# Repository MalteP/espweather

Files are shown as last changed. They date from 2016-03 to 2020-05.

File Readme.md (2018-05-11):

# ESP8266 WiFi Weather Sensor

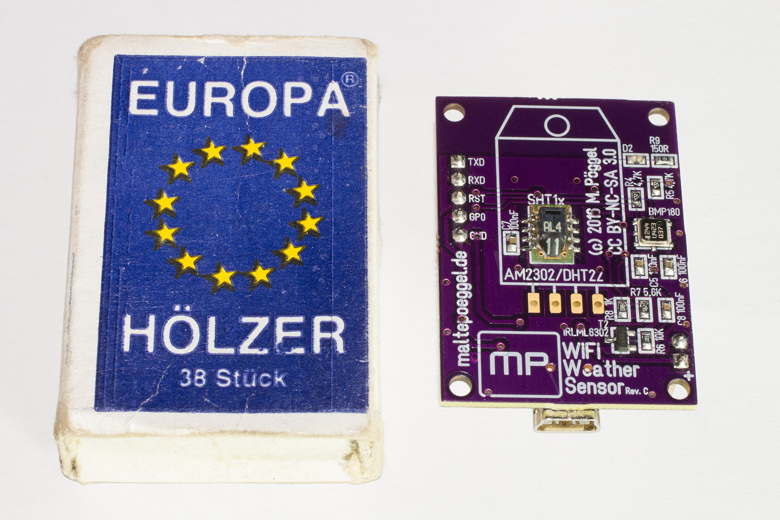
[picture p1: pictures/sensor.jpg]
Picture: ESP8266 WiFi Weather Sensor


## Project overview

The WiFi Weather Sensor is a tiny weather station based on the ESP8266 SOC. It will push the measured temperature, humidity, pressure and battery voltage to the cloud or local servers in defined intervals. Configuration is done by using a simple web browser.

The sensor can be powered using a standard USB power supply or any batteries with a voltage of 3.5 to 6.5V. If inactive, the sensor will enter low power standby. A set of four AA batteries e.g. will last for about one month. The system will also switch off if the voltage drops below 3.0V to safe LiPo batteries. For recharging you might combine it with a solar charger.

## Building the hardware

#### Ordering the parts

Most of the components are available from [Reichelt Elektronik](http://www.reichelt.de/), some more specific parts at [Farnell](http://www.farnell.com/), [Mouser](http://www.mouser.com/) or [Digikey](http://www.digikey.com/). For the ESP-12 (PCB antenna only) or ESP-07 module (PCB antenna + U.FL connector) have a look at [eBay](http://www.ebay.com/) or [Aliexpress](http://www.aliexpress.com/).

As temperature / humidity sensor either SHT11/SHT15 (more accurate) or AM2302/DHT22 (lower price) are possible. The connected sensor is detected automatically. Barometric pressure is measured by using the MS5637 sensor. (Or BMP180 on v1 circuit board)

Here's a list of all components: [Bill of materials (PDF)](documents/parts_v2.pdf)

#### Circuit board

The circuit board is double-sided and plated-through. Because of that i'll recommend ordering it from a PCB manufacturer. Gerber files are included in the GIT repository. Possible good value PCB fabs are [OSH-Park (USA)](http://www.oshpark.com/), [Itead-Studio (China)](http://www.itead.cc/open-pcb.html) or [Dirty Cheap Circuit Boards (China)](http://www.dirtypcbs.com/).

The design is already uploaded to OSH Park, just order it here:

[WiFi Weather Sensor (Version 2) Circuit Board](http://www.oshpark.com/shared_projects/pmVMF4gY)

[WiFi Weather Sensor (Version 1 rev. D) Circuit Board](http://www.oshpark.com/shared_projects/jZi4VgjG)

#### Schematic

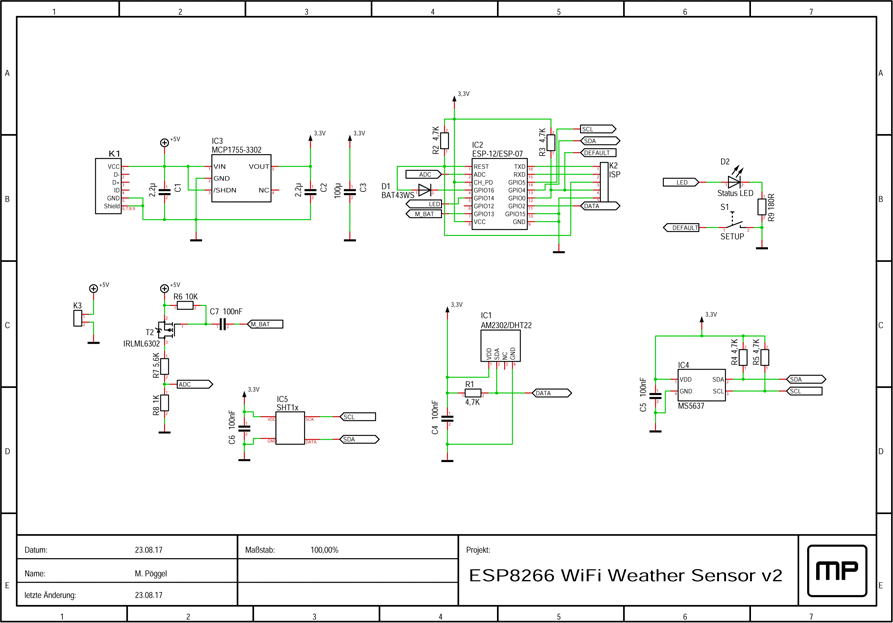
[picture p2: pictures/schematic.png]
Schematic


The LDO IC3 regulates the battery voltage down to 3.3V for power supply of the whole system. Battery voltage is monitored through the voltage divider R7 / R8 which is switched on by FET T2 only during measurement [to reduce power consumption](http://www.jeelabs.org/2013/05/18/zero-power-measurement-part-2/). The barometric pressure sensor MS5637 (IC4) and temperature / humidity sensor SHT11 (IC5) are connected to the ESP8266 module IC2 via I²C bus. Alternatively the temperature / humidity sensor AM2302/DHT22 (IC1) can be used. It is connected using a single wire bus. Status LED (D2) and a setup button (S1) are connected directly to the WiFi module. R3 is used as pull-up resistor for the button, R2 for the reset pin. In low power standby mode XPD_DCDC (GPIO16) is pulled low on wakeup timer event. I've connected it to the reset pin through a shottky diode (D1), because otherwise GPIO16 seemed to be at high level and there was a few ten milliamps of current flowing during reset if flashed via serial connection.

#### Assembling the board

The top side (except for the SHT11 sensor) is soldered in a reflow oven. Just apply solder paste through a CNC cut stencil and bake the board with the appropriate temperature profile. If you don't own a reflow oven, a hot air soldering station might work, too.

The bottom side is assembled using a conventional soldering iron. It's the best practice to start with the smallest components first. If the sensor should run on batteries, don't forget to remove the red LED from the ESP8266 module.

## Preparing the hardware to flash

All ESP8266 modules have a pre-installed bootloader which allows simple firmware flashing via serial connection. A 3.3V TTL USB serial adapter is needed. I recommend those with FT232 chipset.

Connect the pin header of the board to the serial adapter as follows:

| Weather sensor | Serial adapter |
| --- | --- |
| TXD | TXD |
| RXD | RXD |
| RST | RTS |
| GP0 | DTR |
| GND | GND |

## Building the firmware

If you don't want to modify the firmware, you might skip the next steps and [flash the precompiled firmware](#flashing-the-precompiled-firmware).

#### Installing the toolchain

First we will install all necessary packages to compile the toolchain. On a minimal Fedora 26 Linux use the following commands:

```
sudo dnf install make autoconf automake libtool gcc gcc-c++ gperf flex bison texinfo gawk ncurses-devel expat-devel python pyserial python-devel sed git unzip wget bzip2 patch help2man

sudo dnf install http://download1.rpmfusion.org/free/fedora/rpmfusion-free-release-$(rpm -E %fedora).noarch.rpm 
sudo dnf install http://download1.rpmfusion.org/nonfree/fedora/rpmfusion-nonfree-release-$(rpm -E %fedora).noarch.rpm
sudo dnf install unrar
```

If you are using Debian or Ubuntu Linux, [just have a look at the toolchain documentation for installing the needed packages](https://github.com/pfalcon/esp-open-sdk#requirements-and-dependencies). After that you may continue as described below.

Now we're ready to download and compile the ESP8266 toolchain. This process may take a few minutes, depending on your Internet connection and CPU speed, so you better get yourself a cup of tea (or coffee).

```
git clone --recursive https://github.com/pfalcon/esp-open-sdk.git

cd esp-open-sdk
make

cd ..
```

If no errors have occurred, we are ready to finish the installation. I prefer moving the toolchain out of my home directory to /opt, but you may also leave it there and change the paths in the environment variables.

```
sudo mv esp-open-sdk /opt/esp-open-sdk
```

Open your `.bashrc` file with your favorite editor and add the following lines at the end of the file:

```
export PATH=/opt/esp-open-sdk/xtensa-lx106-elf/bin:$PATH
export XTENSA_TOOLS_ROOT=/opt/esp-open-sdk/xtensa-lx106-elf/bin/
export SDK_BASE=/opt/esp-open-sdk/sdk
export ESPTOOL=/opt/esp-open-sdk/esptool/esptool.py
export ESPPORT=/dev/ttyUSB0
```

The changes take effect after a new shell is opened, so log out or open a new terminal window.

#### Installing yui-compressor

yui-compressor is written in Java, so we'll need to install the Java package:

```
sudo dnf install java
```

If you are using Debian or Ubuntu Linux instead of Fedora, [install the OpenJDK JRE.](https://wiki.ubuntuusers.de/Java/Installation/OpenJDK/)

Now download the precompiled .jar file to a folder and also copy it to /opt:

```
mkdir yuicompressor
wget https://github.com/yui/yuicompressor/releases/download/v2.4.8/yuicompressor-2.4.8.jar
mv yuicompressor-2.4.8.jar yuicompressor/yuicompressor.jar
sudo mv yuicompressor /opt/yuicompressor
```

A small wrapper script is needed to execute `yui-compressor` from the `makefile`. Open it with your favorite editor by typing:

```
sudo vi /usr/bin/yui-compressor
```

And add the following lines:

```
#!/bin/sh
java -jar /opt/yuicompressor/yuicompressor.jar $*
```

Now make the script executable:

```
sudo chmod +x /usr/bin/yui-compressor
```

#### Compiling the firmware

Just clone this repository and change into its directory:

```
git clone https://github.com/MalteP/espweather.git
cd espweather
cd firmware
```

Compile the firmware by typing `make`.

```
make
```

Flash firmware and filesystem partition by typing:

```
make flash
make htmlflash
```

If the serial port is not /dev/ttyUSB0, you may add (for example) `ESPPORT=/dev/ttyUSB1` to both `make` commands or change your environment variables.

If the firmware is running, the orange LED on the board should start flashing.

#### Troubleshooting

If the blue LED is constantly flickering, there might be a problem with the calibration data which is stored in flash memory. The position depends on the size of flash determined from the firmware header. Just flash the default calibration data again:

```
make defaultflash
```

After cycling power of the board, the firmware should run fine. The precompiled binary includes calibration data at the correct position.

## Flashing the precompiled firmware

If you don't want to compile the firmware yourself, just skip all "[Building the firmware](#building-the-firmware)" steps above.

You might use [NodeMCU Flasher](https://github.com/nodemcu/nodemcu-flasher) on Windows to flash the precompiled binaries. Open it, change to the "Config" tab and choose the firmware binary by clicking the gear-wheel button. Click the drop-down list on the right side to select the flash section 0x00000. Change back to the "Operation" tab, select the COM port your serial adapter is connected to, and click the "Flash" button.

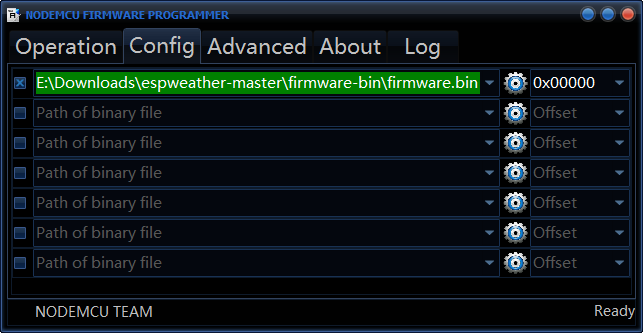
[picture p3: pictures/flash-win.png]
Screenshot: NodeMCU Flasher - Config tab


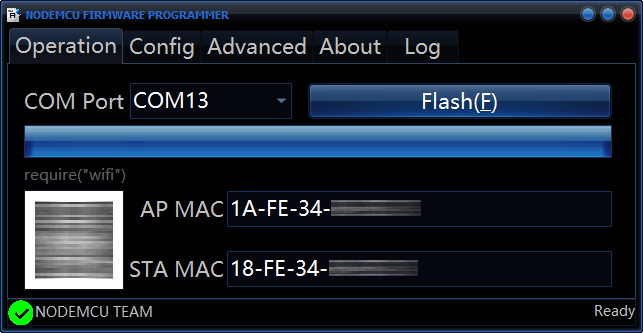
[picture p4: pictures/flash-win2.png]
Screenshot: NodeMCU Flasher - Operation tab


## Hardware setup

There are two modes inside the firmware, normal mode and configuration mode. In normal mode the sensor will measure and push data to the cloud. In configuration mode the sensor acts as wireless access point and is configured via a standard web browser.

#### Normal mode

The sensor will measure temperature, humidity, barometric pressure and battery voltage and push these values to the configured server. After that it will enter deep sleep standby.
At the first start after the battery has been connected, the sensor will stay active for one minute. You may press the button for 3-4sec to switch to configuration mode.

The status is shown by the orange LED, flashing in 1s intervals

| no. of flashes | Status |
| --- | --- |
| 1x | Waiting for WiFi / DHCP |
| 2x | Push data |
| 3x | Server error |
| 4x | First start, waiting |

#### Configuration mode

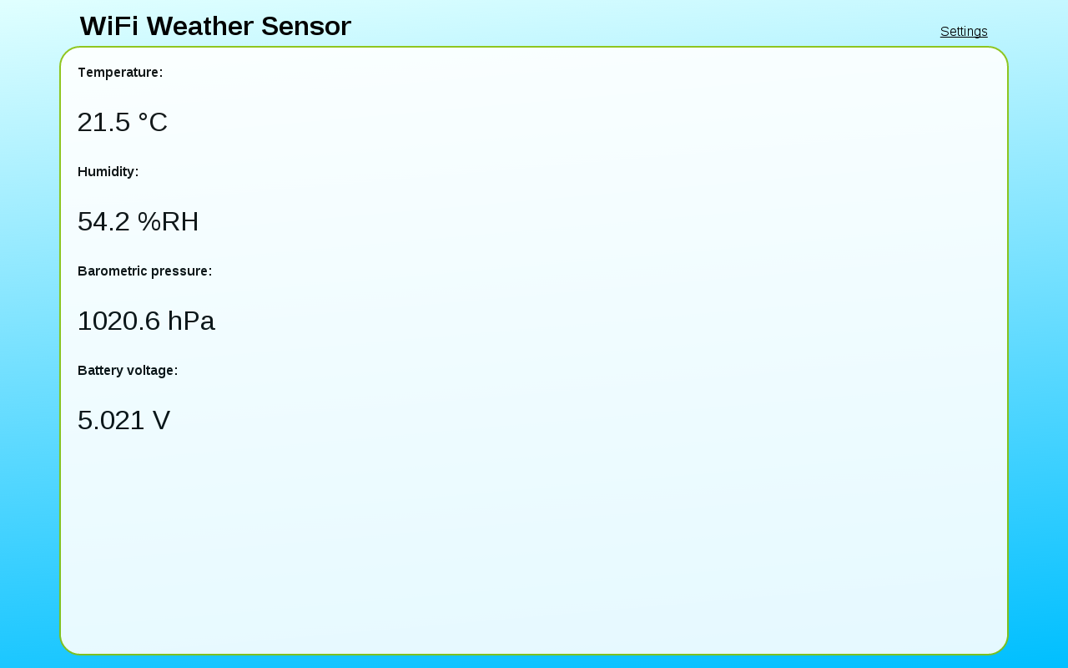
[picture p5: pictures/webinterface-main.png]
Screenshot: Webinterface - Main page


In configuration mode the orange LED will blink at 1Hz clock. Use your computer to connect to the WiFi ESP_xxxx (no encryption) and open http://192.168.4.1/ in your browser.
It will show measured values on the main page, but they may not be very accurate because the WiFi module will heat up the sensors. (This won't affect normal mode because the sensor is only active for ~20sec and will "cool down" during standby periods!)
To leave configuration mode, hold the button for 3-4sec. To erase all configuration data, hold the button for about 10sec.

Click on the button "Settings" at the top right side. The default username is "admin" with password "insecure".

Hint: If you'd like to use an encrypted configuration WiFi, just uncomment the WIFI_PASS definition in user/config.h before compiling.

##### Network settings

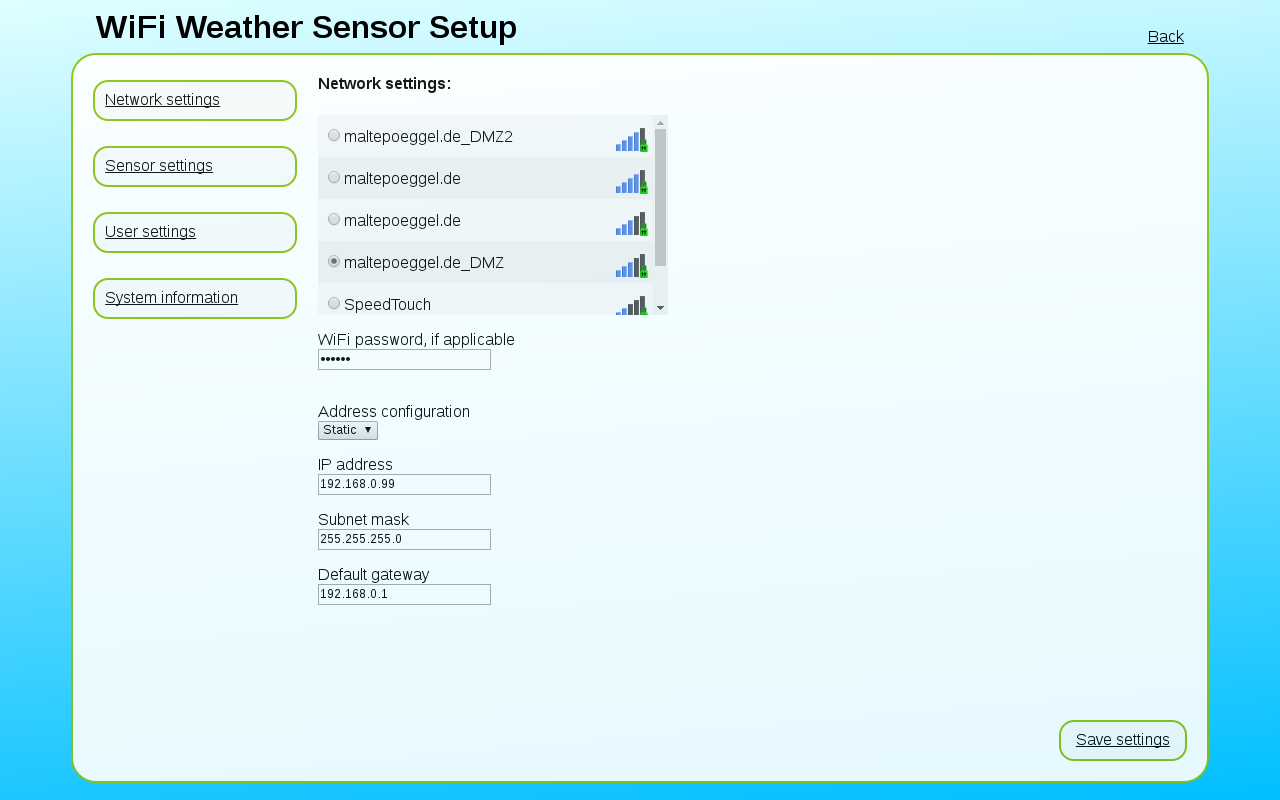
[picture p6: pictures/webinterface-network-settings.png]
Screenshot: Webinterface - Network settings


Just choose the WiFi you want to connect to and enter the password if it is encrypted. 
It might be useful to set up a guest network in your router for security reasons.

##### Sensor settings

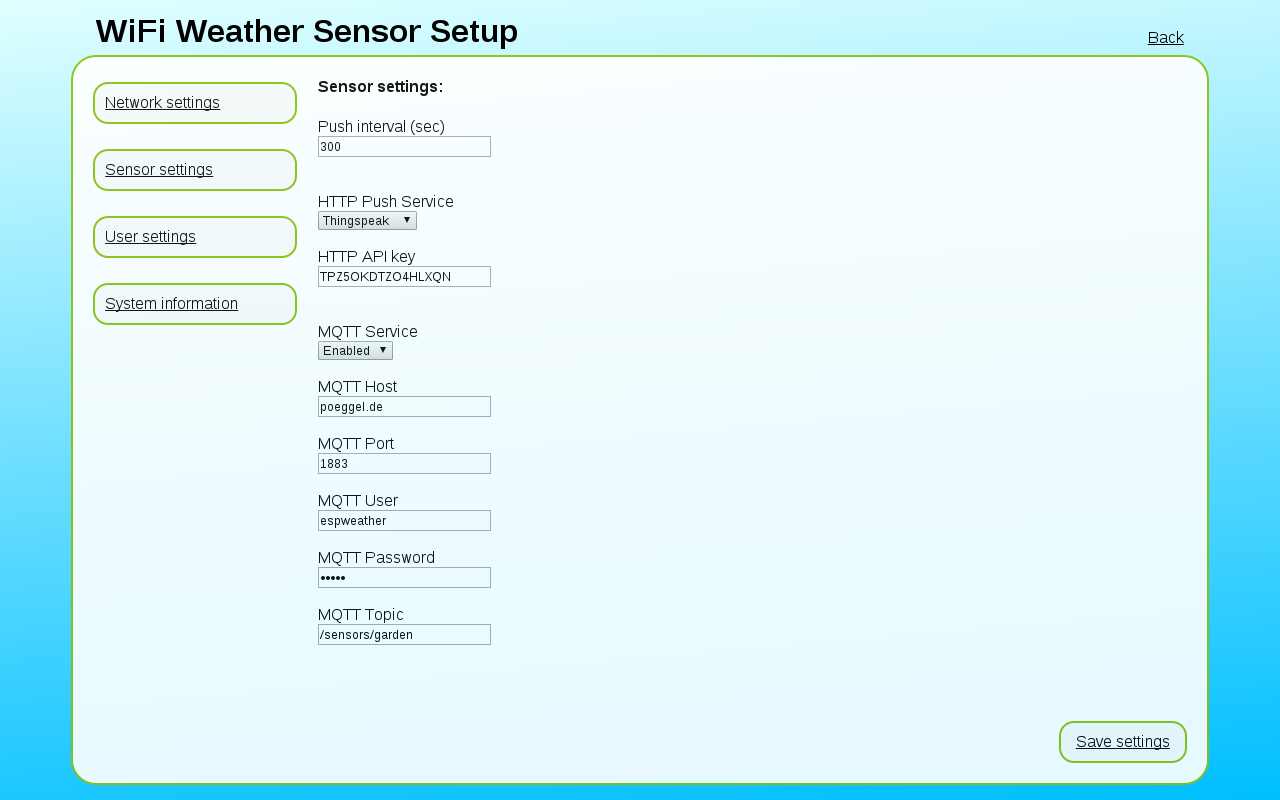
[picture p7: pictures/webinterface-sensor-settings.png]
Screenshot: Webinterface - Sensor settings


On the sensor settings tab, you may change the interval the sensor data is pushed to HTTP and / or MQTT servers. Per default this is set to 300sec (5min).

As cloud services [Thinkspeak](http://www.thingspeak.com/) and [adafruit.io](http://io.adafruit.com/) are available. It is also possible to use a custom URL with placeholders which are replaced by measured values.

| Placeholder | Value |
| --- | --- |
| %t | Temperature |
| %h | rel. Humidity |
| %p | Barometic pressure |
| %v | Battery voltage |
| %r | WiFi signal strength |

If you like to use MQTT, just setup a server software like [mosquitto](http://www.mosquitto.org/) and configure host, port, user and password. The sensor will publish data on [topic]/temperature, /humidity, /pressure, /voltage and /rssi. Different clients may subscribe and receive data immediately after it is published.

##### User settings

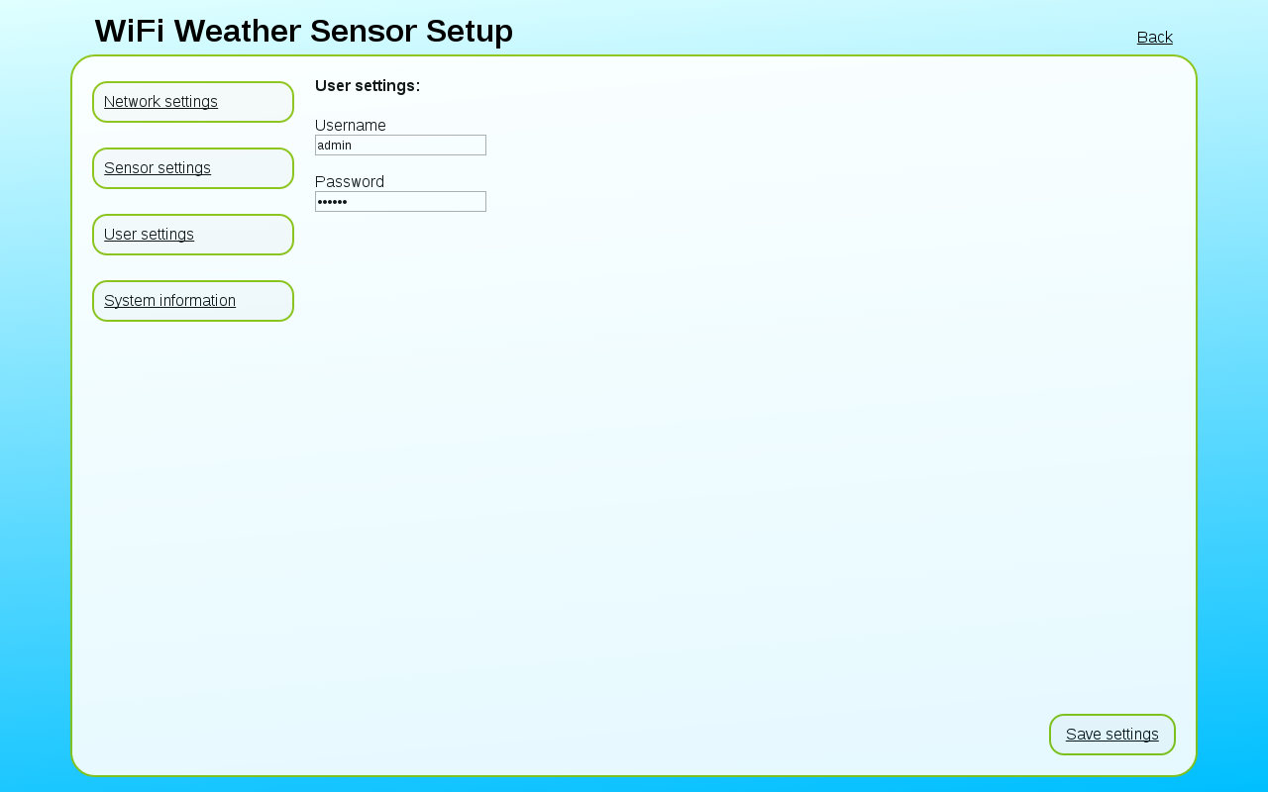
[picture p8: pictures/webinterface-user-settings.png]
Screenshot: Webinterface - User settings


You may change the default username and password for configuration login here.

##### System information

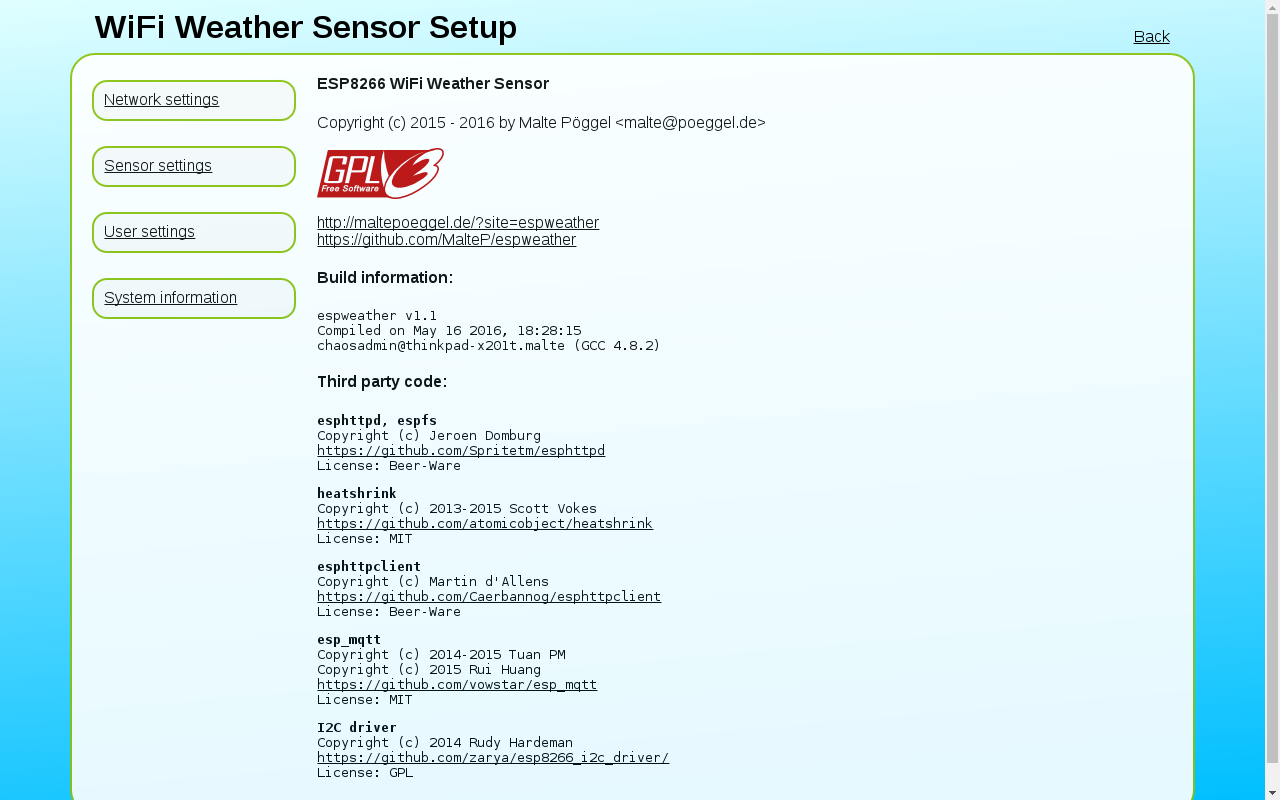
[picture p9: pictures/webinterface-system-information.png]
Screenshot: Webinterface - System information


This shows some nice information about the sensor and code used.

## License

The firmware is released under the terms of [GNU GPL v3](http://www.gnu.org/licenses/gpl-3.0.en.html), circuit board is licensed [CC BY-NC-SA](https://www.creativecommons.org/licenses/by-nc-sa/3.0/).

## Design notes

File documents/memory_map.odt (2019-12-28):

## 4 Mbit (512 KByte)

| Start | End | Size | Description
User | 0x00000 | 0x1FFFF | 131072 bytes | Main application
| | | | firmware/0x00000.bin
| 0x20000 | 0x36FFF | 94208 bytes | ESP filesystem (Web UI)
| | | | Included in main application binary.
SDK | 0x36000 | 0x79FFF | 278528 bytes | SDK libraries
| | | | firmware/0x36000.bin
Config | 0x7A000 | 0x7AFFF | 4096 bytes | Application configuration
| | | | Written by application binary.
| 0x7B000 | 0x7BFFF | 4096 bytes | Calibration data
| | | | blank.bin
| 0x7C000 | 0x7DFFF | 8192 bytes | Default configuration
| | | | esp_init_data_default.bin
| 0x7E000 | 0x7FFFF | 8192 bytes | WiFi configuration
| | | | blank.bin

## 8 Mbit (1024 KByte)

| Start | End | Size | Description
User | 0x00000 | 0x1FFFF | 131072 bytes | Main application
| | | | firmware/0x00000.bin
| 0x20000 | 0x36FFF | 94208 bytes | ESP filesystem (Web UI)
| | | | Included in main application binary.
SDK | 0x36000 | 0xF9FFF | 802816 bytes | SDK libraries
| | | | firmware/0x36000.bin
Config | 0xFA000 | 0xFAFFF | 4096 bytes | Application configuration
| | | | Written by application binary.
| 0xFB000 | 0xFBFFF | 4096 bytes | Calibration data
| | | | blank.bin
| 0xFC000 | 0xFDFFF | 8192 bytes | Default configuration
| | | | esp_init_data_default.bin
| 0xFE000 | 0xFFFFF | 8192 bytes | WiFi configuration
| | | | blank.bin

WiFi Weather Sensor - Flash Memory Map

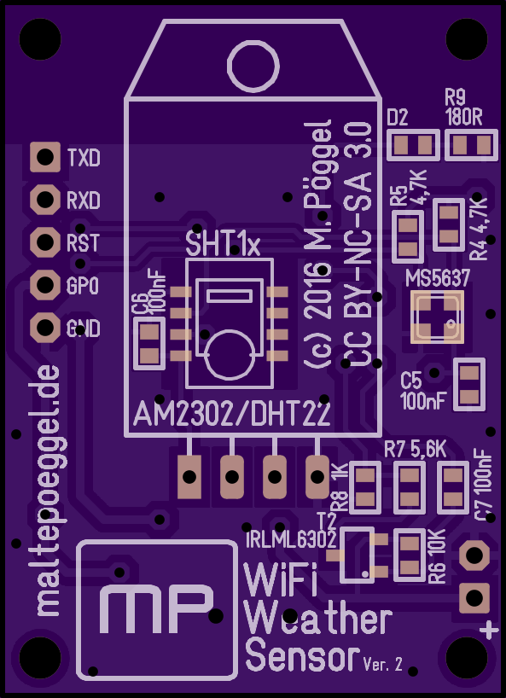
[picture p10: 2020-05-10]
pictures/v2_top.png

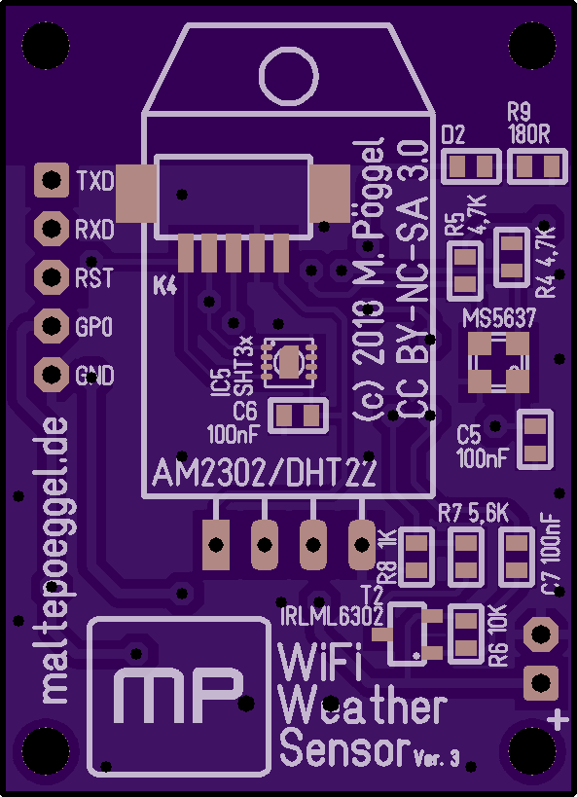
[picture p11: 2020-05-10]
pictures/v3_top.png

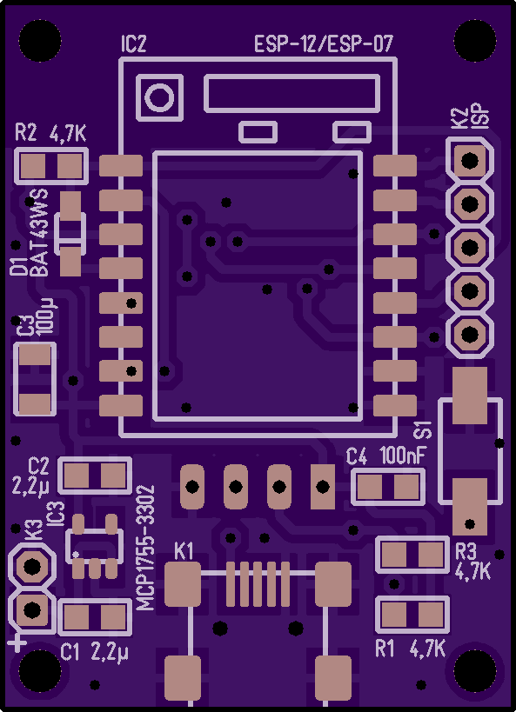
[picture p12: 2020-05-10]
pictures/v3_btm.png

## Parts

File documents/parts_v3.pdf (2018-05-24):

Name | Value | Gehäuse | Bestellnummer | Distributor | Price | Notes
C1 | 2,2µ | 0805 | X7R-G0805 2,2/25 | Reichelt | 0,08 €
C2 | 2,2µ | 0805 | X7R-G0805 2,2/25 | Reichelt | 0,08 €
C3 | 100µ | 1206 | X5R-G1206 100/6 | Reichelt | 0,45 €
C4 | 100nF | 0805 | X7R-G0805 100N | Reichelt | 0,02 €
C5 | 100nF | 0603 | X7R-G0603 100N | Reichelt | 0,02 €
C6 | 100nF | 0603 | X7R-G0603 100N | Reichelt | 0,02 €
C7 | 100nF | 0603 | X7R-G0603 100N | Reichelt | 0,02 €
D1 | BAT43WS | SOD323 | BAT 43WS | Reichelt | 0,05 €
D2 | SMD LED orange | 0603 | LA L296 | Reichelt | 0,15 €
IC1 | AM2302/DHT22 | - | - | eBay | 0,00 € Cheaper sensor. Use either IC1 or IC5
IC2 | ESP-12/ESP-07 | - | - | eBay | 5,00 € ESP07: U.FL jack for external antenna
IC3 | MCP1755-3302 | SOT23/5 | 2361992 | Farnell | 0,62 €
IC4 | MS5637 | | 893-7168 | RS-Components | 4,30 €
IC5 | SHT3x | - | 2474218 | Farnell | 5,75 € More precise measurements than IC1
K1 | Mini USB Type B | - | USB BWM SMD | Reichelt | 0,28 €
K2 | Pin header 1x05 | - | MPE 087-1-005 | Reichelt | 0,12 €
K3 | Pin header 1x02 | - | MPE 087-1-002 | Reichelt | 0,05 €
K4 | 53261-0571 | - | MOLEX 532610571 | Reichelt | 0,28 €
R1 | 4,7K | 0805 | SMD-0805 4,70K | Reichelt | 0,03 €
R2 | 4,7K | 0805 | SMD-0805 4,70K | Reichelt | 0,03 €
R3 | 4,7K | 0805 | SMD-0805 4,70K | Reichelt | 0,03 €
R4 | 4,7K | 0603 | SMD-0603 4,7K | Reichelt | 0,03 €
R5 | 4,7K | 0603 | SMD-0603 4,7K | Reichelt | 0,03 €
R6 | 10K | 0603 | SMD-0603 10K | Reichelt | 0,03 €
R7 | 5,6K | 0603 | SPR-0603 5,60K | Reichelt | 0,25 €
R8 | 1K | 0603 | SPR-0603 1,00K | Reichelt | 0,25 €
R9 | 180R | 0603 | SMD-0603 180 | Reichelt | 0,03 €
S1 | KSR221G SMT Switch | - | 1201421 | Farnell | 0,54 €
T2 | IRLML6302 | SOT23/3 | IRLML 6302 | Reichelt | 0,19 €
PCB | Circuit board | - | - | OSH Park | 3,00 €
21,73 €

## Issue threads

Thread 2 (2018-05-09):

Thingspeak Field 1 & 2 not updating

nabontra, 2018-05-09:
Thank you for sharing your project! I assembled your OSHpark board and uploaded the precompiled firmware. I am getting successful data readouts from all sensors when in configuration mode through the ESP Access Point. When using the Thingspeak API, only fields 3 and 4 seem to be making it through. I am assuming the protocols have changed on Thingspeak in the past two years since they have been purchased by MathWorks, but it looks like the only API change are to an HTTPS domain. Have you experienced this recently?
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

MalteP, 2018-05-09:
Hi Nick,
which type of temperature / humidity sensor are you using?

MalteP, 2018-05-09:
I've fixed some timing issues in #b80f9c2 which might cause the first read of DHT22 sensors to fail. You'll better use the development branch firmware, but there currently are no precompiled binaries. I'll check my ESP toolchain and send you an email, just give me a few minutes ;-)

MalteP, 2018-05-16:
Did the development firmware solve your issue?

Closed 2019-01-22.

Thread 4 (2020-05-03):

Humidity data in Thingspeak occasionally missing

DK3LJ, 2020-05-03:
Hardware is espweather v3 with current firmware 221-8m.bin, sensor is AM2302.

ESPweather is set up to feed data into Thingspeak with 5 fields: (temperature, humidity, pressure, voltage, RSSI) in 5 minute intervals. Power supply is via USB cable from a USB charger.

In most cases, humidity data is missing from the data in Thingspeak. However, after a reboot (with or without going into config mode to check the data), the next few tramsissions are fine, then drop off again.

Feeds CSV export is attached. Any ideas?

[feeds.txt](https://github.com/MalteP/espweather/files/4570643/feeds.txt)

MalteP, 2020-05-03:
As the AM2302 is of very poor quality, resolution and there is no long time stability data available from the manufacturer, i would suggest to use **any** other sensor if possible.

Prices for the BME280 dropped, so this would be my choice for low budget sensors. I can provide crimped cables with Molex / Jumper connectors if you are interested. (Hint: Select address 0x77 by soldering the solder bridge on the "GYBMEP" board to +3V) Btw: My favourite sensor combination is MS5637 / SHT35.

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

SDK 2.2.1 is supported since the last commit. Might be timing issues; might be long cables. Are there any other sensors on your circuit board (e.g. barometric pressure)?

The sensor selection code will default to the sensor with the highest resolution available, so if the AM2302 is not detected properly, you might get the temperature readings from your MS5637.

Please test if the values are also missing in the SDK 2.1.0 version i sent you. If so, we'll need to analyze the protocol with a storage oscilloscope and fine-tune timing parameters in dht22.h. And maybe build a version with some debug printf()'s. But i don't have much time because i'm working on other projects right now...

MalteP, 2020-05-05:
I did some testing and found out that i can reproduce your issue. When the board is booted up, my logic analyzer doesn't show me any response from the sensor when opening /sensors.cgi (which fetches the sensor data in config mode) directly in my browser. After some minutes the sensor is suddenly responding. But if the board is then rebooted, the communication breaks again.

After that i played around with the start pulse length, added 100nF or 10µF capacitors to the sensor, changed the pull up resistor value; no success...

Then i found a board with an old sensor (maybe bought it years ago when i started developing this project) and desoldered it. I changed the sensor in my test setup to the old one. It is always read out. After every reset, there are no problems at all!

Maybe the new sensor is fake, maybe they changed the firmware, but i guess we can not fix this hardware issue in the DHT22 driver...

Btw there are similar reports for the Tasmota project:
https://github.com/arendst/Tasmota/issues/3187

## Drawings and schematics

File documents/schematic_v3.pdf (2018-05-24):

D+ | 3 D- | 2 VCC | 1 K1

A

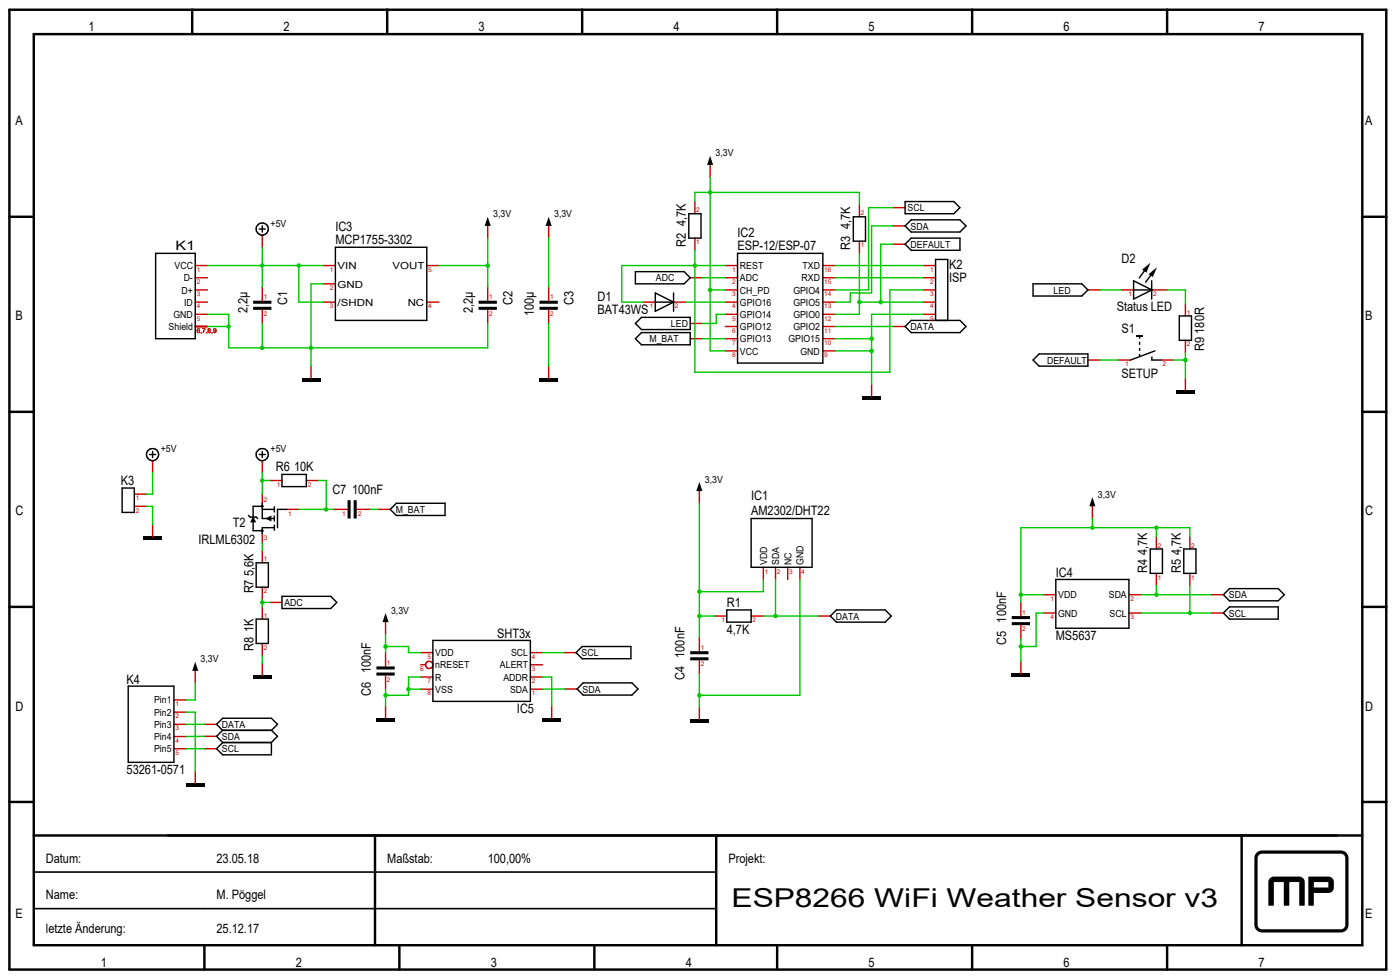
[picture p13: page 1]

Datum: 23.05.18 | Maßstab: 100,00% | Projekt:

Name:

letzte Änderung: 25.12.17

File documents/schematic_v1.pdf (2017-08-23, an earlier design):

K1

A

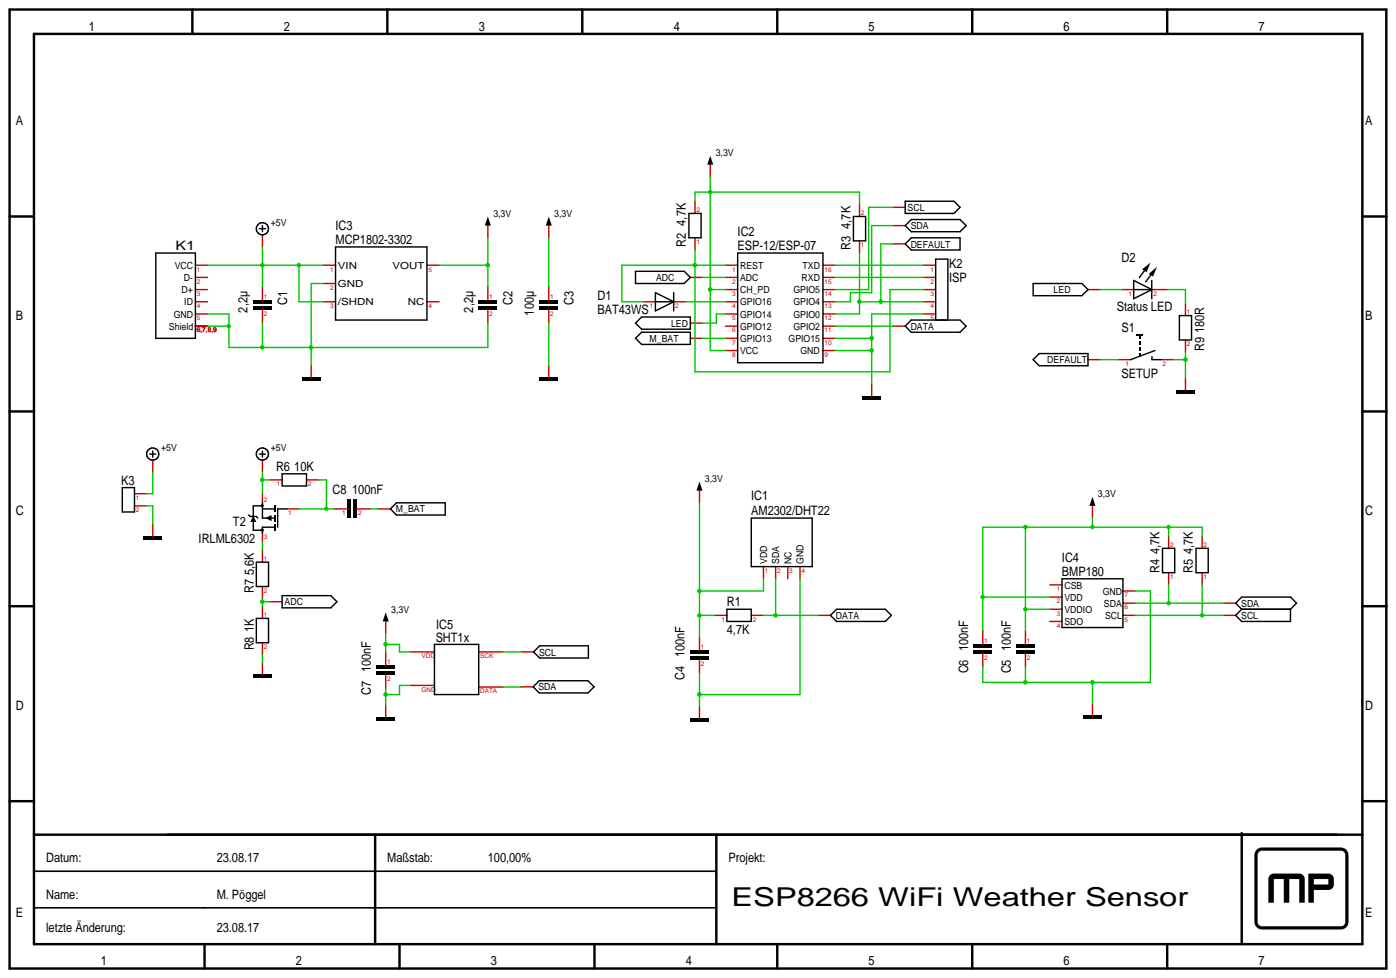
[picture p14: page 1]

Datum: 23.08.17 | Maßstab: 100,00% | Projekt: ESP8266 WiFi Weather Sensor
M. Pöggel Name:

letzte Änderung: 23.08.17

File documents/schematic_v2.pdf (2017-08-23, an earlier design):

K1

A

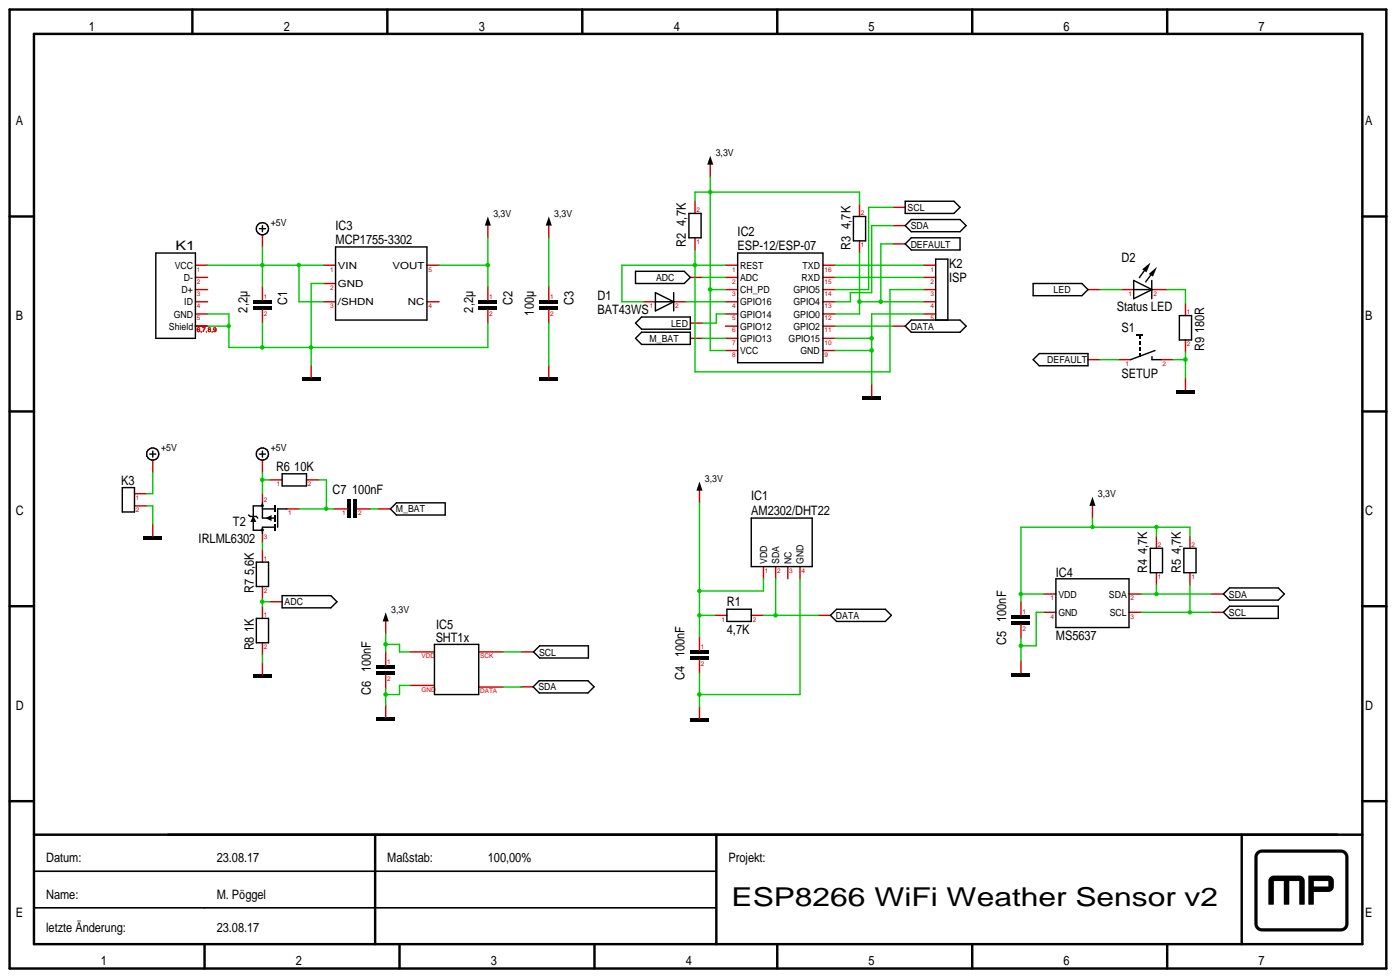
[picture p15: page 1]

Datum: 23.08.17 | Maßstab: 100,00% | Projekt: ESP8266 WiFi Weather Sensor v2
M. Pöggel Name:

letzte Änderung: 23.08.17

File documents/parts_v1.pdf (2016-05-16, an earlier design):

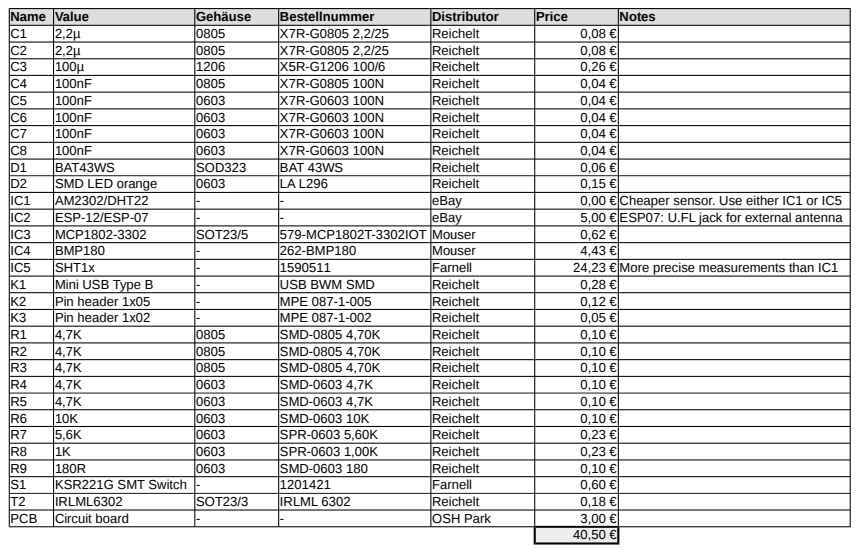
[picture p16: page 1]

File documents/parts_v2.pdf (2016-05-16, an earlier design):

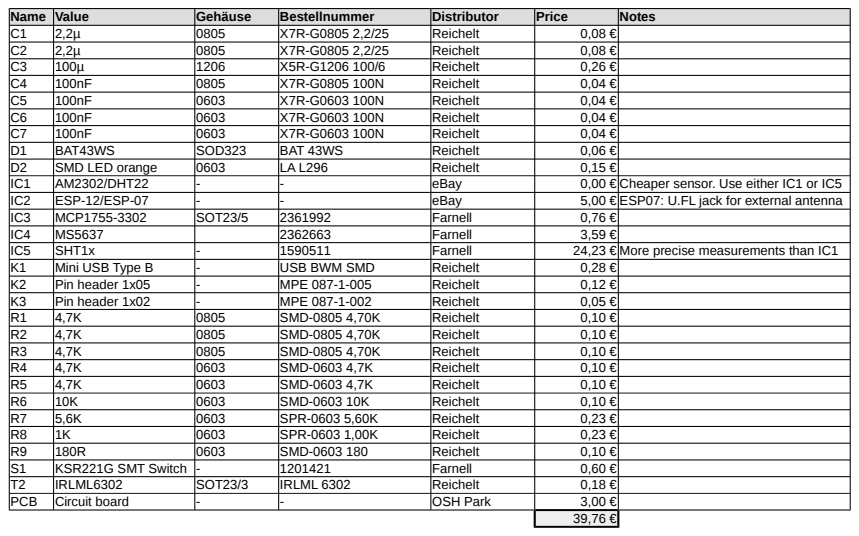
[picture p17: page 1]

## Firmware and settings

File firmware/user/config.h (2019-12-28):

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
#ifndef CONFIG_H
 #define CONFIG_H

 // GPIO pin for config button
 #define BTNGPIO 0

 // GPIO for status LED
 #define LEDGPIO 14

 // RTC magic value for detecting first start
 #define RTC_MAGIC 0xC0DEBABE

 // Sensor modes
 #define MODE_NORMAL 0
 #define MODE_CONFIG 1
 #define MODE_DEFAULT MODE_NORMAL

 // Hide all passwords in setup?
 #define HIDE_PASS
 #define HIDE_PASS_STRING "******"

 // Default user for login
 #define ADMIN_USER "admin"
 #define ADMIN_PASS "insecure"

 // Push interval & initial settings
 #define INT_DEFAULT 300
 #define HTTP_ENABLED 0
 #define MQTT_ENABLED 0

 // Default data for cloud service

 #define URL_DEFAULT "http://example.com/sensor.php?temperature=%t&humidity=%h&pressure=%p&voltage=%v&rssi=%r"
 #define KEY_DEFAULT ""
 #define GRP_DEFAULT ""

 // Default data for MQTT
 #define MQTT_HOST   "example.com"
 #define MQTT_PORT   1883 
 #define MQTT_USER   ""
 #define MQTT_PASS   ""
 #define MQTT_TOPIC  "sensors/0"

 // Config STA password (Unencrypted if not defined)
 //#define WIFI_PASS   "ESP_Weather"

 // Default data IP configuration
 #define WIFI_DHCP   1
 #define WIFI_IP     "192.168.0.99"
 #define WIFI_MASK   "255.255.255.0"
 #define WIFI_GW     "192.168.0.1"

 // LED status
 #define LED_OFF     0
 #define LED_FLASH1  1
 #define LED_FLASH2  2
 #define LED_FLASH3  3
 #define LED_FLASH4  4
 #define LED_BLINK   5

 // Configuration structure stored in flash
 // (Length must be multiple of 4 bytes because of SPI flash page structure)
 typedef struct
  {
   char chksum;
   uint8_t sensor_mode;
   uint16_t sensor_interval;
   char admin_user[32];
   char admin_pass[32];
   uint8_t http_enabled;
   char http_key[64];
   char http_grp[64];
   char http_url[128];
   uint8_t mqtt_enabled;
   char mqtt_host[64];
   uint16_t mqtt_port;
   char mqtt_user[64];
   char mqtt_pass[64];
   char mqtt_topic[64];
   uint8_t wifi_dhcp;
   char wifi_ip[16];
   char wifi_mask[16];
   char wifi_gw[16];
   char pad[3];
  } MyConfig;

 void configInit( void );
 void configLoad( void );
 void configSave( void );
 void configReset( void );
 MyConfig* configGet( void );
 uint8_t configIsFirstStart( void );
 void configCheckWifiMode( void );
 void configSetWifiMode( int mode );
 void configRestart( void );
 void configInitIP( void );
 void configInitSoftAP( void );
 void configInitReconnectPolicy( void );
 void statusLed( uint8_t mode );

#endif

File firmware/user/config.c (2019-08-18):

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
#include <esp8266.h>
#include "config.h"

static MyConfig myConfig;
static ETSTimer configBtnTimer;
uint8_t firstStart;
uint8_t ledStatus, ledLastState;
uint8_t ledMode;

char calcChksum( void );
void configBtnTimerCb( void *arg);
void configRestartCb( void *arg );
void statusLedCb( void );


// Initialize configuration
void ICACHE_FLASH_ATTR configInit( void )
 {
  uint32_t rtcmagic = 0;
  // Clear config data
  memset(&myConfig, 0, sizeof(MyConfig));
  // Check for first start
  // This is done by storing a magic number inside the RTC register, which will
  // store its values during low power standby as long as the battery is connected.
  firstStart = 0;
  system_rtc_mem_read(128, &rtcmagic, 4);
  if(rtcmagic!=RTC_MAGIC)
   {
    rtcmagic=RTC_MAGIC;
    system_rtc_mem_write(128, &rtcmagic, 4);
    firstStart = 1;
   }
  // Init button
  PIN_FUNC_SELECT(PERIPHS_IO_MUX_GPIO0_U, FUNC_GPIO0);
  os_timer_disarm(&configBtnTimer);
  os_timer_setfn(&configBtnTimer, configBtnTimerCb, NULL);
  os_timer_arm(&configBtnTimer, 500, 1);
  // Init LED
  ledStatus = 0;
  ledLastState = 0;
  ledMode = LED_OFF;
  PIN_FUNC_SELECT(PERIPHS_IO_MUX_MTMS_U, FUNC_GPIO14);
  GPIO_OUTPUT_SET(LEDGPIO, 0);
 }


// Load config from flash
void ICACHE_FLASH_ATTR configLoad( void )
 {
  int c;
  spi_flash_read(ESP_PARAM_SEC*SPI_FLASH_SEC_SIZE, (uint32 *)&myConfig, sizeof(MyConfig));
  c=calcChksum();
  if (c!=myConfig.chksum)
   {
    os_printf("Checksum mismatch. Loading default config!\n");
    configReset();
   }
 }


// Save config to flash
void ICACHE_FLASH_ATTR configSave( void )
 {
  myConfig.chksum=calcChksum();
  spi_flash_erase_sector(ESP_PARAM_SEC);
  spi_flash_write(ESP_PARAM_SEC*SPI_FLASH_SEC_SIZE, (uint32 *)&myConfig, sizeof(MyConfig));
 }


// Reset configuration to defaults
void ICACHE_FLASH_ATTR configReset( void )
 {
  struct station_config stconf;
  // Reset user config
  memset(&myConfig, 0, sizeof(MyConfig));
  myConfig.sensor_mode = MODE_DEFAULT;
  myConfig.sensor_interval = INT_DEFAULT;
  os_strcpy(myConfig.admin_user, ADMIN_USER);
  os_strcpy(myConfig.admin_pass, ADMIN_PASS);
  myConfig.http_enabled = HTTP_ENABLED;
  os_strcpy(myConfig.http_key, KEY_DEFAULT);
  os_strcpy(myConfig.http_grp, GRP_DEFAULT);
  os_strcpy(myConfig.http_url, URL_DEFAULT);
  myConfig.mqtt_enabled = MQTT_ENABLED;
  os_strcpy(myConfig.mqtt_host, MQTT_HOST);
  myConfig.mqtt_port = MQTT_PORT;
  os_strcpy(myConfig.mqtt_user, MQTT_USER);
  os_strcpy(myConfig.mqtt_pass, MQTT_PASS);
  os_strcpy(myConfig.mqtt_topic, MQTT_TOPIC);
  // Reset WLAN settings
  myConfig.wifi_dhcp = WIFI_DHCP;
  os_strcpy(myConfig.wifi_ip, WIFI_IP);
  os_strcpy(myConfig.wifi_mask, WIFI_MASK);
  os_strcpy(myConfig.wifi_gw, WIFI_GW);
  memset(&stconf, 0, sizeof(stconf));
  wifi_station_set_config(&stconf);
 }


// Return pointer to configuration
MyConfig* ICACHE_FLASH_ATTR configGet( void )
 {
  return &myConfig;
 }


// First start after battery was connected?
uint8_t ICACHE_FLASH_ATTR configIsFirstStart( void )
 {
  return firstStart;
 }


// Check and modify WiFi mode if necessary
void ICACHE_FLASH_ATTR configCheckWifiMode( void )
 {
  int mode = wifi_get_opmode();
  if(myConfig.sensor_mode==MODE_NORMAL)
   {
    if(mode!=1)
     {
      configSetWifiMode(1); // STA
      wifi_set_sleep_type(MODEM_SLEEP_T); // Save some power
     }
   } else {
    if(mode!=3)
     {
      configSetWifiMode(3); // AP+STA
      wifi_set_sleep_type(NONE_SLEEP_T); // No sleep possible
     }
   }
 }


// Set WiFi mode and restart
void ICACHE_FLASH_ATTR configSetWifiMode( int mode )
 {
  os_printf("Setting WIFI Mode to %d...\n", mode);
  wifi_station_disconnect();
  wifi_set_opmode(mode);
  configRestart();
 }


// Delayed restart
void ICACHE_FLASH_ATTR configRestart( void )
 {
  static ETSTimer configWifiTimer;
  GPIO_OUTPUT_SET(LEDGPIO, 0);
  os_timer_disarm(&configBtnTimer);
  // Delay restart
  os_timer_disarm(&configWifiTimer);
  os_timer_setfn(&configWifiTimer, configRestartCb, NULL);
  os_timer_arm(&configWifiTimer, 1000, 0);
}


// Callback for restart timer
void ICACHE_FLASH_ATTR configRestartCb( void *arg )
 {
  system_restart();
 }


// WiFi IP address configuration
void ICACHE_FLASH_ATTR configInitIP( void )
 {
  struct ip_info info;
  os_memset(&info, 0x0, sizeof(info));
  // DHCP configuration disabled?
  if(myConfig.wifi_dhcp==0)
   {
    wifi_station_dhcpc_stop();
    info.ip.addr = ipaddr_addr(myConfig.wifi_ip);
    info.netmask.addr = ipaddr_addr(myConfig.wifi_mask);
    info.gw.addr = ipaddr_addr(myConfig.wifi_gw);
    wifi_set_ip_info(STATION_IF, &info);
   }
 }
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

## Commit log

2016-04-07 Added support for MS5637, improved sensor detection
2016-05-13 Updated readme: Remove red LED
2016-05-16 Added macros for battery measurement FET GPIOs
2016-05-16 Updated documentation for v2 board
    [parts.ods, parts_v1.ods, parts_v2.ods]
2016-05-16 Add files for circuit board v2
    [espweather.GBL, espweather.GBO, espweather.GBS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]
2016-12-17 Handle delayed sensor read and HTTP redirects
2017-08-23 GPIO4 / GPIO5 swapped in schematic
2017-08-23 Fix compile with latest toolchain / esptool, changed memory map
    [config.h]
2017-08-23 Remove repeat flag from reboot timer after mode change
    [config.c]
2017-10-22 Cleanup I2C stuff
2017-10-25 Switch to own I2C implementation
2017-10-30 Add support for SHT30/31/35 temperature / humidity sensor
2017-10-30 Fix SHT3x sensor reading
2017-11-14 Only delay DHT sensor
2017-12-18 Fix sign issue <0 >-1
    [sensors.h]
2018-05-10 Fix build with NONOS SDK 2.1
    [i2c-common.c, sht1x.c]
2018-05-16 Remove signedness of I2C read functions, change pressure sensor data variable names
2018-05-17 Change pressure sensor function names
2018-05-19 Add BMP/BME280 driver
2018-05-21 Sensor detection completely rewritten
2018-05-22 Fix BMP280 wrong temperature / overflow
    [bmx280.c]
2018-05-24 Add v3 layout and schematic
    [espweather3.GBL, espweather3.GBO, espweather3.GBS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]
2019-02-20 Improve sensor.cgi JSON output
2019-02-20 Reduce power consumption through pullup in SHT1x driver
2019-05-16 Fix connection problems in configuration AP mode if configured wireless network is down
    [config.c]
2019-08-18 Reduce size of i2c-common lib
2019-12-28 Add missing ICACHE_FLASH_ATTR to some i2c functions
    [i2c-common.c]
2019-12-28 Fix Makefile for SDK 2.2.1, support for 8Mbit flash
    [config.h]
2020-05-10 Improve DHT22 error message
    [dht22.c]
2020-05-10 Add silkscreen images for different board revisions, will be added to the documentation later
2020-05-10 Add macros for return values of sensor functions
2020-05-10 Add "pending" sensor state, handle as soft failure (does not increment the failed counter, but will retry to read), some more macros for return values
    [dht22.c, sensors.h]

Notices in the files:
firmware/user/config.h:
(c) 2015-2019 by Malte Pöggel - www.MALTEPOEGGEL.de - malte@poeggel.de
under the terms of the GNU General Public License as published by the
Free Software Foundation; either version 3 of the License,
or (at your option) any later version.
